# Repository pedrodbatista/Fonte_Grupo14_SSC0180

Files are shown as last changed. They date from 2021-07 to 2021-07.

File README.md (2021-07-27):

# Projeto de Eletrônica - Fonte Váriavel de 3-12V / 100mA
* **Disciplina:** *SCC0180* - Eletônica para Computação (2021)
* **Professor:** Eduardo do Valle Simões (simoes@icmp.usp.br)

### Grupo
Projeto realizado pelo Grupo 14:
* Fábio Verardino de Oliveira - N. USP: 12674547
* Fabio Henrique Alves Cavaleti - N. USP: 11200550
* Gabriel Fachini - N. USP: 11953481
* Pedro Dias Batista - N. USP: 10769809

---

## Especificações
Para o projeto, deve ser construída uma fonte de retificadora de tensão contínua e variável, entre 3V e 12V. Além disso a fonte deve ser capaz de fornecer 100mA. A entrada da fonte é uma onde senoidal de corrente alternada, com tensão de 127V e frequência de 60Hz.

## Desenvolvimento do circuito
A teoria por traz dos estágios da fonte variável, além dos cálculos que leveram à escolha dos valores dos componentes estão expostas no seguinte documento: [PDF Trabalho de Eletrônica](assets/Trabalho_Eletronica.pdf).

## Circuito no Simulador Falstad
O circuito foi construído no simulador online [Falstad](http://falstad.com/circuit/circuitjs.html), a fim de confirmar o funcionamento da fonte e ajustar os valores dos componentes.

O circuito do projeto pode ser acessado no seguinte link: [Fonte Variável - Falstad][9].

[9]: http://falstad.com/circuit/circuitjs.html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

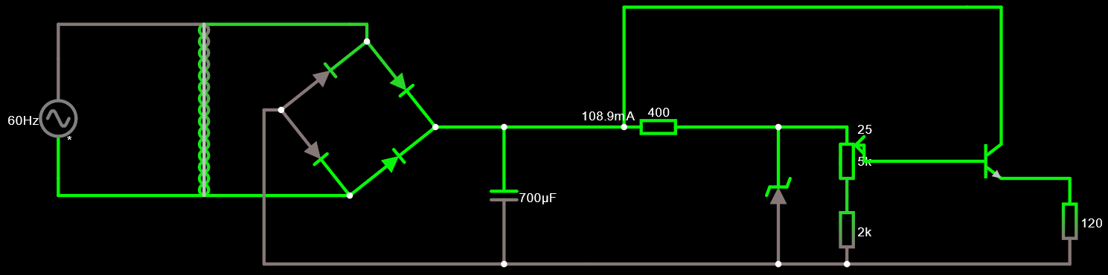
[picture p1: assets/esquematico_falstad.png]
Imagem do circuito no Falstad


## Esquemático e PCB do circuito no Autodesk EAGLE
Após a simulação do circuito. Foi construído um esquemático do circuito no software Autodesk EAGLE, com o intuito de criar, depois, um modelo da placa de circuito da fonte.

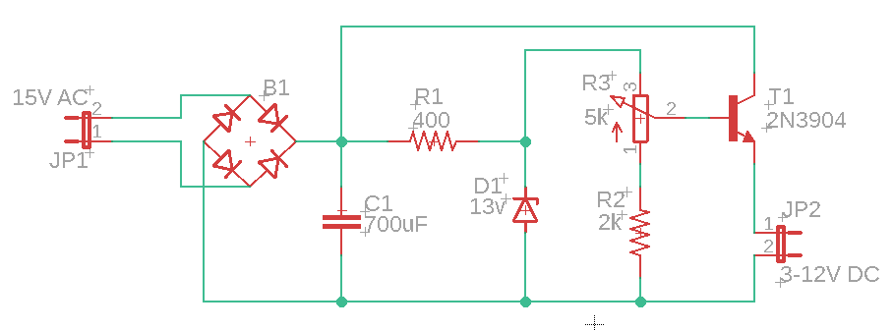
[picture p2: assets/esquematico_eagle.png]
Esquemático do circuito no EAGLE


A partir desse esquemático, o mesmo software foi utilizado para montar o modelo da PCB do circuito da fonte.

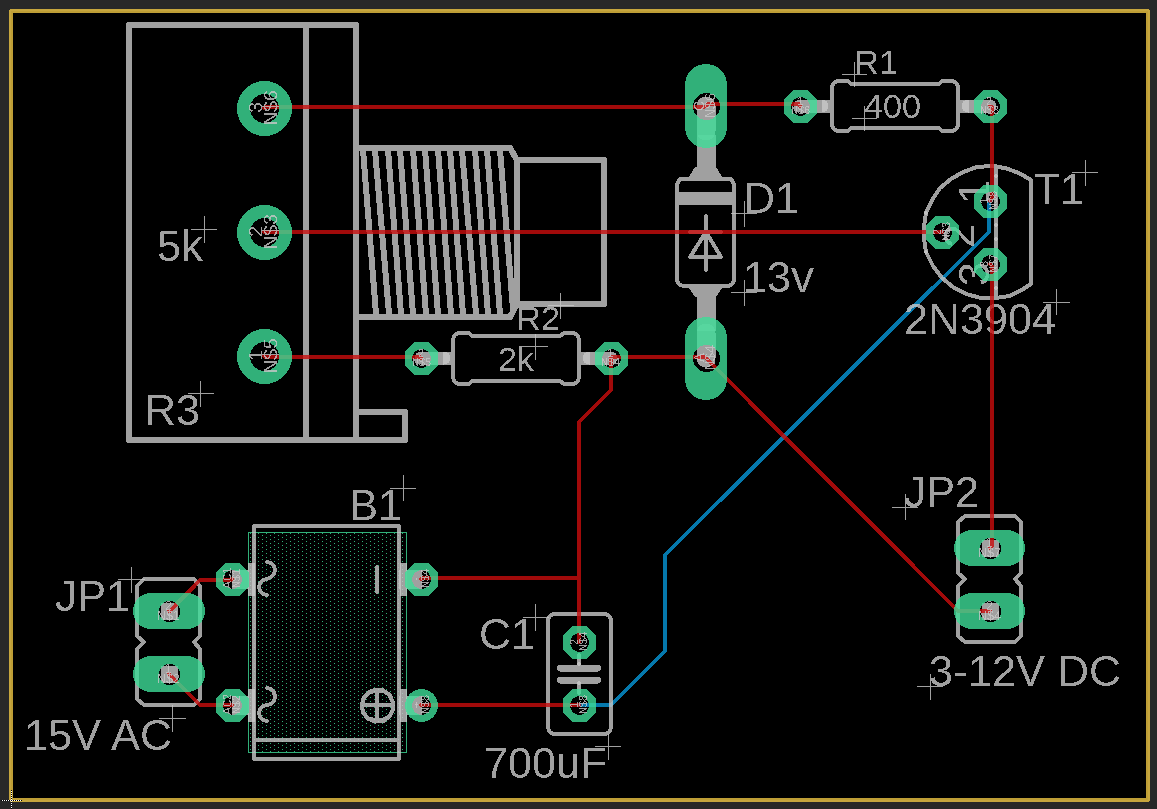
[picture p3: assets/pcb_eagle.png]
Esquemático da placa de circuito no EAGLE


* O transformador foi deixado de fora do esquemático pois ocupa muito espaço. O jumper JP1 representa os pontos de conexão da bobina secundária.
* Os arquivos do projeto no EAGLE estão no repositório do projeto.

## Componentes utilizados

A lista a seguir contém os componentes utilizados na montagem da fonte, além de links para comprá-los e seus preços:

| Componente | Especificações |Quantidade | Preço Unitário | Total |
|--- |--- |--: |---: |---: |
| [Transformador][1] | 127V -> 18V | 1 | R$ 27.99 | R$ 29.99 |
| [Capacitor][2] | 1mF / 25V | 1 | R$ 0.46 | R$ 0.46  |
| [Diodo][3] | 1N4007 | 4 | R$ 0.10 | R$ 0.40  |
| [Resistor][4] | 330Ω | 1 | R$ 0.18 | R$ 0.18  |
| [Resistor][5] | 2kΩ | 1 | R$ 0.05 | R$ 0.05  |
| [Diodo Zener][6] | V<sub>Z</sub> = 13V | 1 | R$ 0.19 | R$ 0.19  |
| [Potênciometro][7] | 5kΩ | 1 | R$ 1.99 | R$ 1.99  |
| [Transistor][8] | 2N2222 | 1 | R$ 0.26 | R$ 0.26  |
| | | |**Total** | R$ 33.52 |

[1]: https://www.soldafria.com.br/transformador-18v-500ma-entrada-110-220vac
[2]: https://www.baudaeletronica.com.br/capacitor-eletrolitico-1000uf-25v.html
[3]: https://www.baudaeletronica.com.br/diodo-1n4007.html
[4]: https://www.baudaeletronica.com.br/resistor-330r-5-1w.html
[5]: https://www.baudaeletronica.com.br/resistor-2k-5-1-4w.html
[6]: https://www.baudaeletronica.com.br/diodo-zener-1n4743-13v-1w.html
[7]: https://www.baudaeletronica.com.br/potenciometro-linear-de-5k-5000.html
[8]: https://www.baudaeletronica.com.br/transistor-npn-2n2222.html

* Alguns dos valores dos componenetes foram alterados para atender à disponibilidade do mercado. O funcionamento da fonte não é prejudicado ao utilizar-se desses componentes.

## Vídeo explicativo

Também foi gravado, pelos integrantes do grupo, um vídeo explicando o funcionamento do circuito e dos componentes que o compõem, além dos calculos realizados para a escolha daqueles.

* [Vídeo do projeto](https://youtu.be/JVlfiyRQYMs)

---

## Agradecimento

Os integrantes do grupo gostariam de agradecer ao professor Eduardo Simões e ao monitor Gabriel Kuabara por toda a ajuda durante a realização do projeto.

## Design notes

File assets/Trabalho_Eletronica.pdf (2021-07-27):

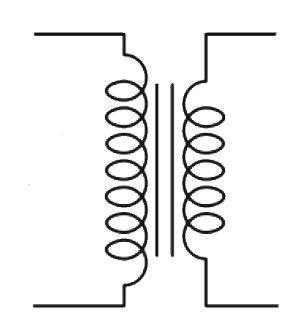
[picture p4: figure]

Trabalho eletrônica | 1

⚡

# Trabalho eletrônica

# Componentes da fonte

O objetivo da nossa fonte de tensão regulável é utilizar a tensão de 127v, com corrente alternada de uma tomada, e a transformarmos em uma tensão regulável com valores que vão de 3 a 12 volts com corrente contínua.

## Transformador

Os transformadores são dispositivos que transportam energia elétrica de um circuito para outro.

Como pode ser visto na figura, o transformador tem dois conjuntos de espiras: o enrolamento primário, ligado ao circuito que vai transmitir a energia, com

Simbolo de um transformador

N1 espiras e o enrolamento secundário, ligado ao circuito que vai receber a energia elétrica, o qual conta com espiras..
Ele funciona baseado nos principios do eletromagnetismo: Pela lei de Indução de Faraday, a tensão do primeiro circuito induz tensão no segundo circuito. Não existe conexão elétrica entre os dois circuitos. Podemos controlar a tensão do segundo circuito controlando o número de espiras da cada lado do transformador conforme as equações abaixo:

❗ Observe que o transformador apenas reduz o valor da tensão. Ou seja, a corrente continua sendo alternada.

## Retificador de onda completa

O circuito retificador de onda completa vai lidar com a corrente alternada utilizando uma ponte de diodos. Os diodos sao dispositivos que permitem a passagem de corrente em apenas um sentido.

Com esta disposição de diodos, o circuito consegue lidar tanto com parte positiva, quanto com a negativa, conseguindo passar corrente para o circuito sem se importar com a fase da corrente alternada.

N2

= (1.1)
V2

V1
N1

N2

= (1.2)
I1

I2
N2

N1

A tensão que é aplicada aos terminais da carga deve ser diminuída de duas vezes , pois sempre terá 2 diodos entre a carga e a fonte.

A expressão encontra - se em módulo, pois o retificador de onda completa sempre mantém o mesmo sentido da corrente, ou seja a tensão é sempre positiva.

📌 No circuito de retificador de onda completa:
→ O sentido da corrente na carga é o mesmo nas duas fases do ciclo. → Não há períodos de interrupção da tensão, exceto quando a onda passa pelo zero.

A tensão observada na carga de um retificador de onda completa tem as seguintes características:
→ A frequência é o dobro da frequencia da tensão fornecida pela fonte.
→ O perído equivale à metade do período da tensão fornecida pela fonte.
→ A tensão de pico vale | , onde | é a tensão de pico da
fonte.
→ A tensão efetiva vale
→ A fase se mantém.

## Capacitores

Um capacitor é composto por duas placas condutoras separadas por um material isolante. Ele consegue armazenar energia na forma de campo elétrico.

VD

VR(t) = ∣(VP − 2VD )Sen(ωt)∣

Vp − 2VD | VP
Vef = | 2 VP −2VD

💡 Quando uma tensão é aplicada sobre o capacitor, ela não consegue atravessá - lo, por conta do material isolante. Isso cria um campo elétrico no capacitor induzindo carga negativa na outra placa do capacitor. Quando a corrente cessar, a carga permanecerá armazenada entre as placas, até que uma tensão no sentido contrário seja imposta.

→ Ao ficar completamente carregado, o capacitor se comporta como uma resistência de valor muito alto. Isso ocorre por conta de que a corrente em um capacitor depende do tempo de carga:

### Carga de um capacitor

A tensão em um capacitor é dependente do tempo segundo uma exponencial.

### Descarga de um capacitor

Simobologia dos capacitores

IC = =
dt

dQ
C
dt

dVC

⁍

### Capacidade de um capacitor para um ripple de 10%

Onde | é a corrente de saída em ampéres, | é o valor da tensão de entrada
em Volts, é a frequência da corrente alternada em Hertz, e | é a capacidade
do capacitor em Farads.

# Diodos de Zener

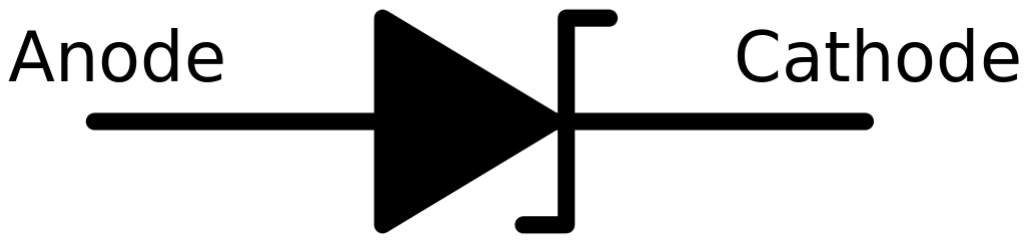
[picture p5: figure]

É um tipo especial de diodo, pois permite a passagem de corrente no sentido de polarização inversa. Entretanto, a corrente no sentido inverso sempre mantém a tensão em um valor fixo, denominado tensão de Zener . A tensão de Zener é característica do diodo.

VC = VR

VC = VR = RC
dt

dVC

VC = VR = V0e RC

−t

I = e R

V0

RC

−t

C =
Vsf

5Io

Io | Vs
f | C

(VZ )

# Potenciômetro

Trata - se de um resistor com resistência variável. Este será utilizado na regulagem da fonte, para que póssamos controlar a voltagem fornecida pela mesma.

# Transistores de junção

Os transistores de junção são criados de maneira semelhante ao diodo, a partir de cristais de silício. Desse modo, assim como os diodos, o transistor também é composto por regiões N, caracterizada pela presença de elétrons, e regiões P, caracterizada pela presença de lacunas(falta de elétrons). Entretanto, enquanto que os diodos são compostos por duas regiões: uma N e uma P, os transistores são compostos por 3 regiões criando, dessa forma, duas possibilidades de transistores: NPN e PNP.
Um transistor tem 3 terminais, denominados base, coletor e emissor, os quais estão conectados a cada uma das regiões N ou P.

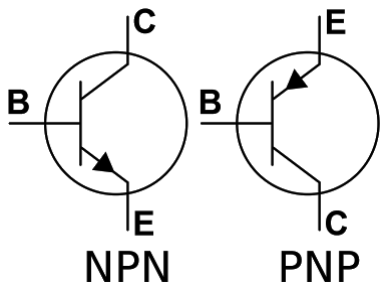
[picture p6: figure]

# Projeto da fonte

Conhecendo um pouco melhor sobre o funcionamento dos componentes de uma fonte de tensão regulada, somos capazes de criar nosso projeto de fonte

Simbologia transistores NPN e PNP que conta com algumas etapas: Transformador, retificação, filtragem e regulação.

## Transformador

Essa etapa é a responsável por diminuir a tensão inicial de 127 volts, que vem da tomada, para uma tensão mais próxima da desejada utilizando um transformador. Lembrando que o transformador apenas irá reduzir a tensão inicial, ou seja, a tensão continuará sendo alternada.

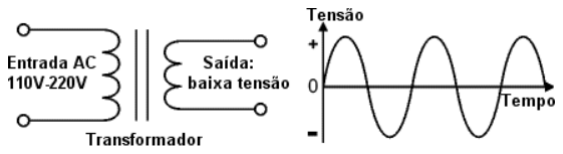
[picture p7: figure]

## Retificação

Na retificação, iremos utilizar uma ponte de diodos para lidar com a mudança de fase da corrente alternada. Desse modo, teremos um fluxo de corrente em apenas um sentido. Entretanto, nossa tensão ainda será variável, oscilando entre uma tensão máxima de pico e uma tensão equivalente a 0.

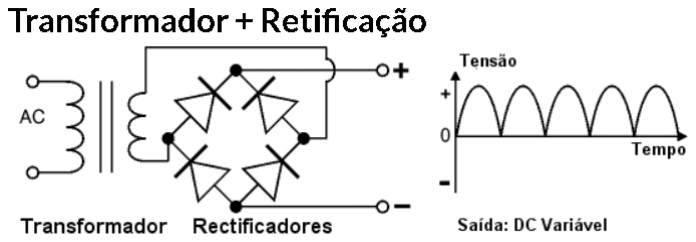
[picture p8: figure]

## Filtragem

Agora vamos lidar com a variação da tensão. Vamos utilizar um capacitor, o qual irá carregar com a tensão variável recebida após a retificação e vai

Fonte: https://www.electronica-pt.com/fontes-alimentacao/teoria-fontes-alimentacao

Fonte: https://www.electronica-pt.com/fontes-alimentacao/teoria-fontes-alimentacao descarregar uma tensão o mais próximo de contínua quanto possível. Porém, como a tensão do capacitor cai um pouco nas descargas, não é possível obter uma tensão ou corrente completamente contínua. Observa - se uma pequena variação chamada de Ripple.

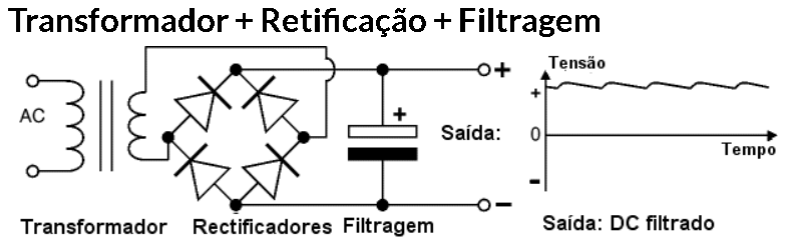
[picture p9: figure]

## Regulação

Aqui vamos tentar reduzir a tensão de Ripple o máximo possível e criar uma possibilidade de regulagem de tensão. Para tanto, temos que utilizar um cricuito regulador de tensão, criado com um diodo de Zener, um transistor NPN, 3 resistores e 1 potenciômetro. Com isso, seremos capazes de regular e alternar nossa fonte entre os valores de 3 a 12 volts.

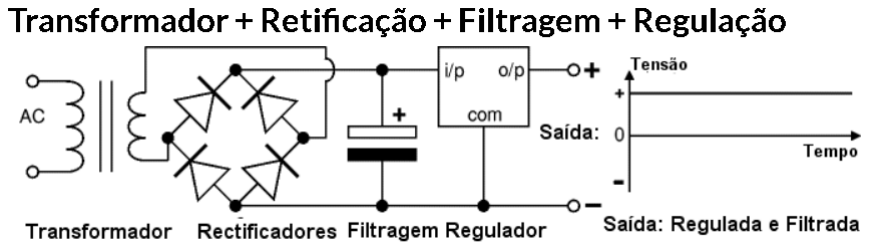
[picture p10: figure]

# Cálculos realizados no projeto

## Transformador

Fonte: https://www.electronica-pt.com/fontes-alimentacao/teoria-fontes-alimentacao

Fonte: https://www.electronica-pt.com/fontes-alimentacao/teoria-fontes-alimentacao

Precisamos saber a razão entre as voltagens. Escolhemos uma voltagem próxima de 17,5 V para ser obtida pelo transformador. Dessa forma, temos:

Resolvemos, portanto, aproximar a razão do transformador para 0,14. Com isso, nosso circuito do falstad alega uma tensão de pico de 17,359 V.

## Ponte de diodos

A ponte retificadora de onda completa conta com dois diodos funcionando no circuito a todo momento. Dessa forma, temos que descontar 0,65 V para cada diodo utilizado no circuito. Como temos 2 diodos no circuito, temos que descontar 1,3 Volts da tensão obtida pelo transformador:

Nosso circuito no falstad registrou uma tensão de pico de 16,617 Volts na saída da ponte retificadora.

## Capacitor

Para o capacitor, iremos calcular sua capacitância buscando um ripple de 10% ou menos. Iremos utilizar a fórmula já apresentada para obtermos o cálculo da capacitância para um ripple de 10%.
Vamos utilizar como | a tensão de pico obtida pelo circuito do falstad : 16,6 V.
Para | vamos utilizar 110 miliampéres. Pois queremos que nossa fonte
entregue 100 miliampéres para o dispositivo.
Sabemos portanto que precisamos de pelo menos | para atendermos os
requesitos do nosso projeto. Com o intuito de buscar um ripple menor e
atender valores comerciais, decidimos utilizar um capacitor de | .
Portanto:

≈
127

17, 5
0, 138

⁍

Vs

Io

C = | =
16, 6 ∗ 60

5 ∗ 110 ∗ 10⁻³
552 μF

552 μF

700 μF

Na saída do capacitor, nosso circuito no falstad apresenta um corrente muito próxima a 110 miliampéres.

## Diodo de zener

Nosso diodo de zener terá uma tensão de zener de 13 volts, valor bem próximo do valor máximo fornecido pela fonte.

# Resistores e potenciômetro

Para ajustar a regulagem da tensão fornecida pela fonte iremos utilizar um potenciômetro de 5k ohms, um resistor de 400 ohms e um resistor de 2k ohms.

C = 700 μF

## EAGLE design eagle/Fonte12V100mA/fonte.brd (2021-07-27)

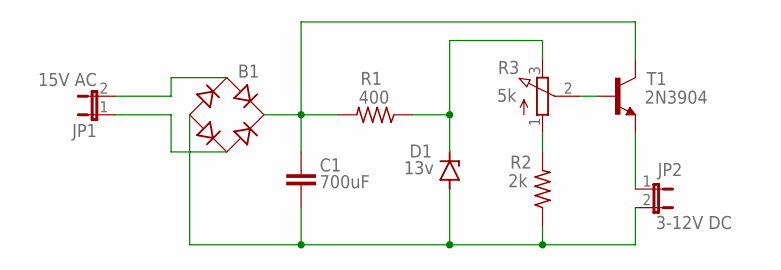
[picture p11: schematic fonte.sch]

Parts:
B1: B-DIL
C1: 700uF; C025-025X050
D1: 13v; SOD81
JP1: 15V AC; JP1
JP2: 3-12V DC; JP1
R1: 400; 0204/7
R2: 2k; 0204/7
R3: 5k; 3RP/1610N
T1: 2N3904; TO92

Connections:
unnamed: B1.AC1, JP1.2
unnamed: B1.AC2, JP1.1
unnamed: R3.2 (S), T1.2 (B)
unnamed: B1.-, C1.2, D1.A, JP2.2, R2.1
unnamed: R2.2, R3.1 (A)
unnamed: D1.C, R1.1, R3.3 (E)
unnamed: JP2.1, T1.3 (E)
unnamed: B1.+, C1.1, R1.2, T1.1 (C)

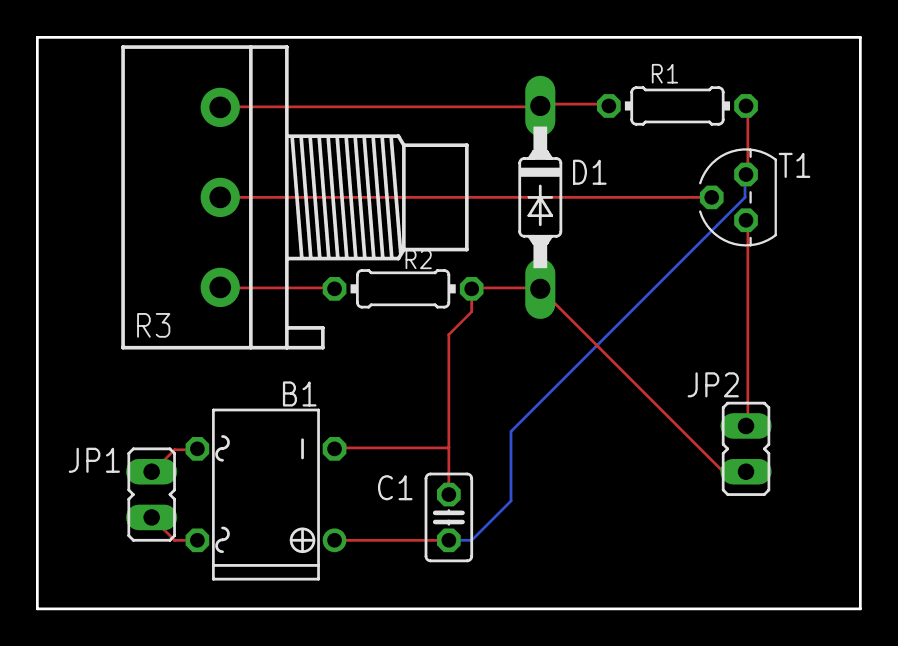
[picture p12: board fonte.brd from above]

Board: 2 copper layers, 45.7 x 31.8 mm, 9 parts (0 on the bottom side), 8 nets.
